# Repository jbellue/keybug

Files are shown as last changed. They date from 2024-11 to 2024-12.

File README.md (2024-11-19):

# Keybug - a small 5-keys macro keypad

It was initially designed to handle a debugger (Start/Stop/Step Into/Step Out/Step).

It runs [RMK](https://github.com/HaoboGu/rmk) (free vial!), but will be extremely simple to add to QMK. I might do that someday.

## Default Keymap

Here it is with the default keys to debug on IntelliJ:

```text
╭──────┬──────┬──────┬──────┬──────╮
│ Ctrl │  F9  │  F8  │  F7  │ Shft │
│  F2  │      │      │      │  F8  │
╰──────┴──────┴──────┴──────┴──────╯
```

## Remapping

Remapping is done through [Vial](https://vial.rocks/) on a browser supporting WedHID (i.e. Chrome).

Due to the way RMK works, reflashing probably doesn't update the keymap.

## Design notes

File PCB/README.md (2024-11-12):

# Keybug's PCB

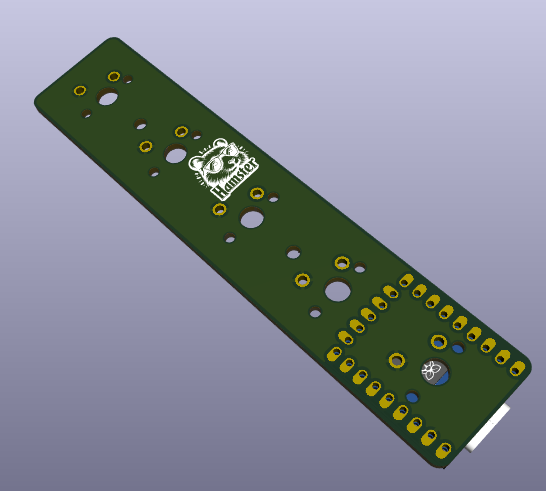
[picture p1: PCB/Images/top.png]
top view of the PCB
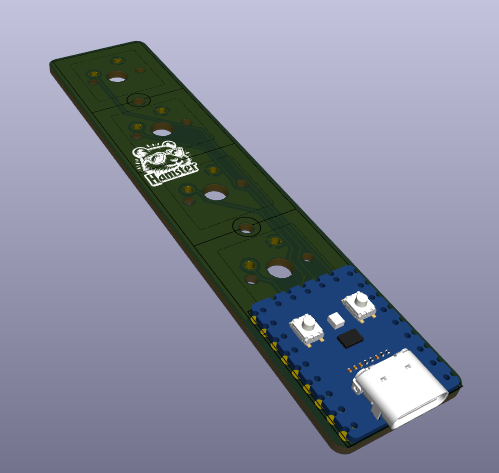
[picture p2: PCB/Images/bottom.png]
bottom view of the PCB
 

Built in Kicad8, using files from [Crides' Kleeb](https://github.com/crides/kleeb)

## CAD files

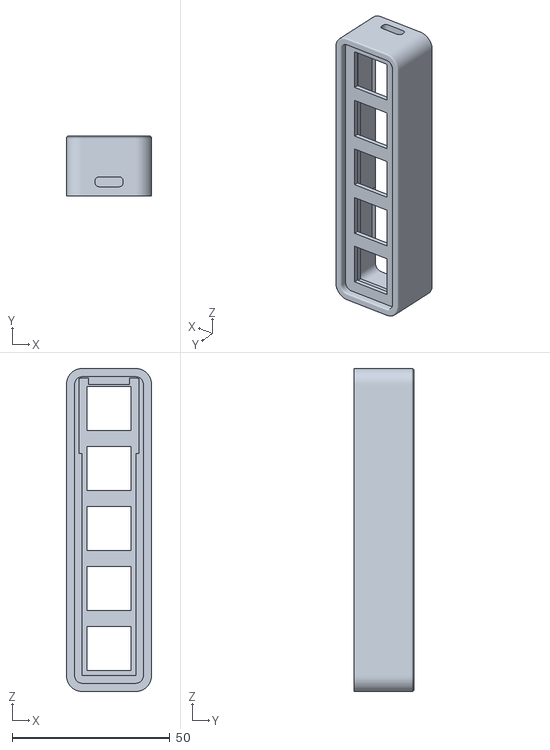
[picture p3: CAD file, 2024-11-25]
case/top.stl
27.0 x 19.0 x 102.5

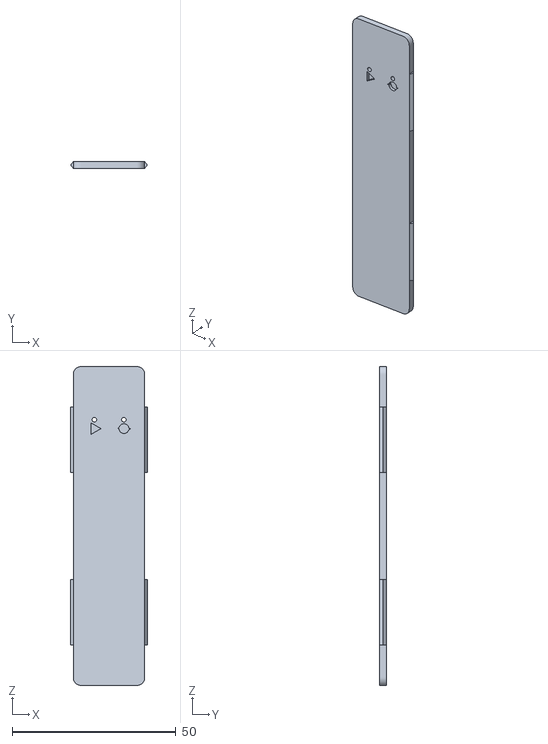
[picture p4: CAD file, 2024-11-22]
case/bottom.stl
23.4 x 2.00 x 97.3

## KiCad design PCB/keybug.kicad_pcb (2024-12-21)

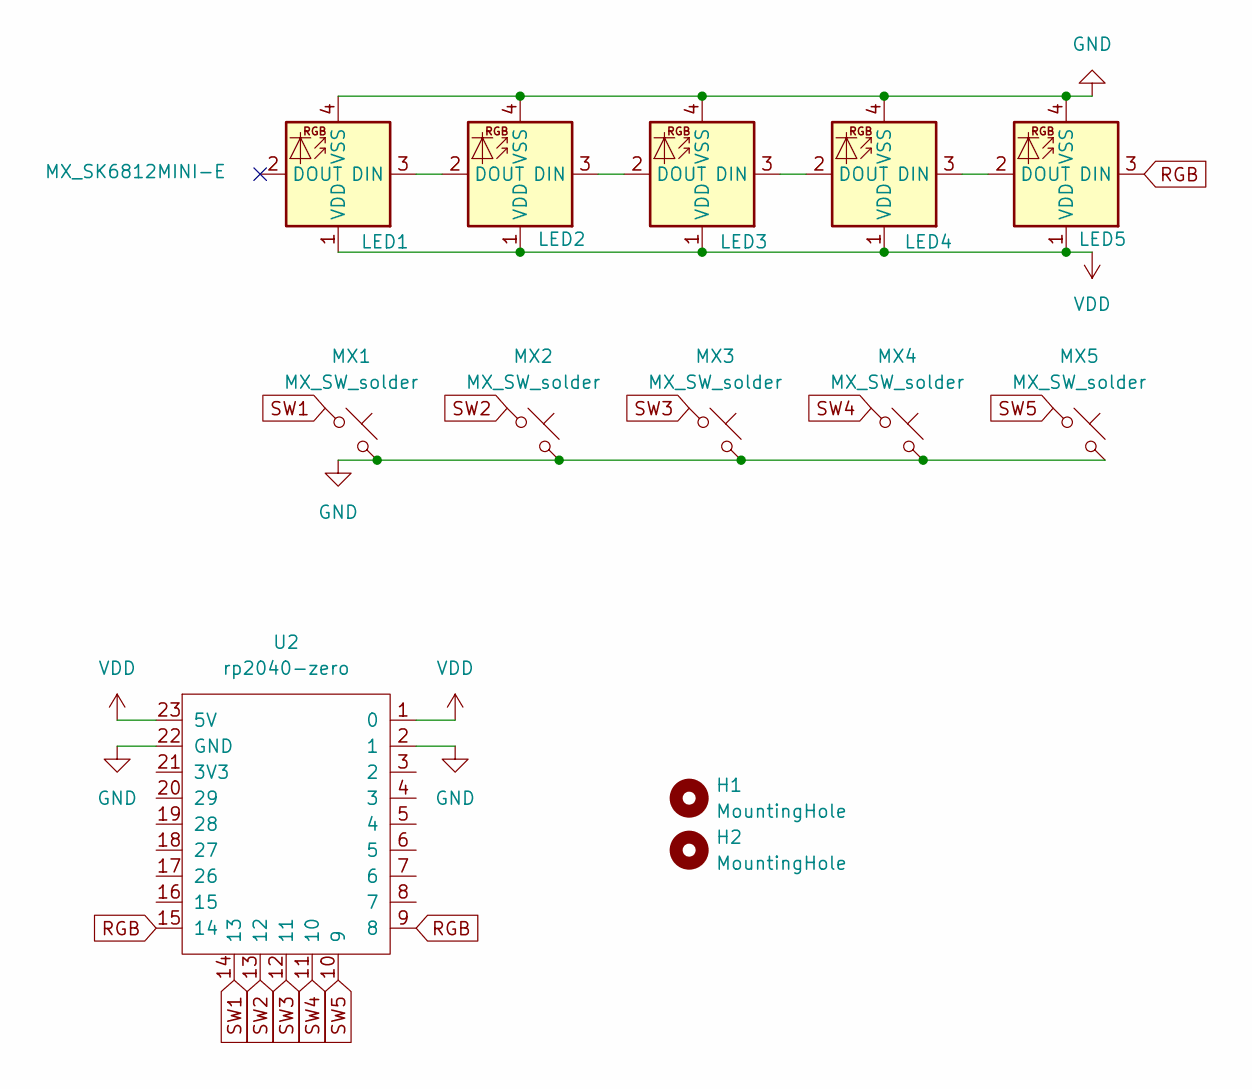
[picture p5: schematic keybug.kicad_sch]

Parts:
H1, H2: MountingHole; MountingHole_2.2mm_M2
LED1, LED2, LED3, LED4, LED5: MX_SK6812MINI-E; LED_MX_6028R-ROT
MX1, MX2, MX3, MX4, MX5: MX_SW_solder; SW_MX_1u
U2: rp2040-zero; rp2040-zero-tht

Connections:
GND: LED1.4 (VSS), LED2.4 (VSS), LED3.4 (VSS), LED4.4 (VSS), LED5.4 (VSS), MX1.2, MX2.2, MX3.2, MX4.2, MX5.2, U2.2 (1), U2.22 (GND)
unnamed: LED1.3 (DIN), LED2.2 (DOUT)
unnamed: LED2.3 (DIN), LED3.2 (DOUT)
unnamed: LED3.3 (DIN), LED4.2 (DOUT)
unnamed: LED4.3 (DIN), LED5.2 (DOUT)
RGB: LED5.3 (DIN), U2.9 (8), U2.15 (14)
SW1: MX1.1, U2.14 (13)
SW2: MX2.1, U2.13 (12)
SW3: MX3.1, U2.12 (11)
SW4: MX4.1, U2.11 (10)
SW5: MX5.1, U2.10 (9)
VDD: LED1.1 (VDD), LED2.1 (VDD), LED3.1 (VDD), LED4.1 (VDD), LED5.1 (VDD), U2.1 (0), U2.23 (5V)

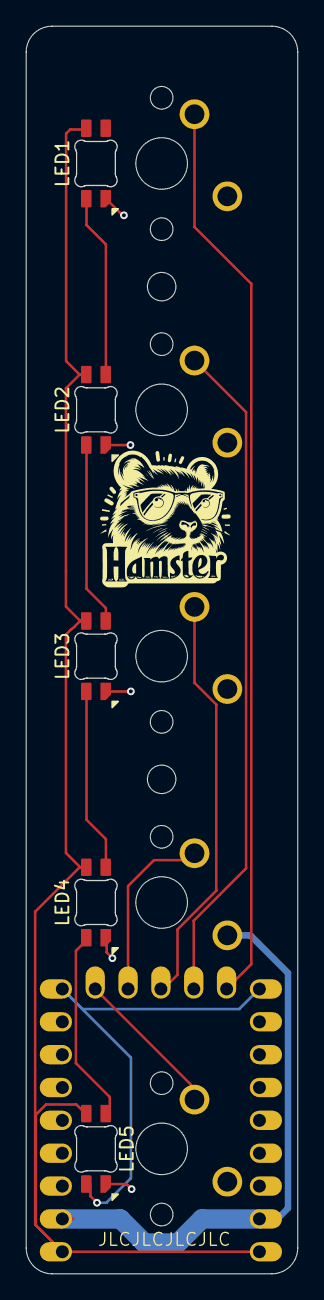
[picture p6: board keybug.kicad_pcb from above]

Board: 2 copper layers, 21.0 x 96.5 mm, 13 parts (0 on the bottom side), 12 nets.

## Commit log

2024-11-12 Add case
    [bottom.stl, top.stl]
2024-11-12 Add PCB
    [keybug.kicad_pcb, keybug.kicad_sch]
2024-11-22 PCB - put switches pads on both sides...
    [keybug.kicad_pcb]
2024-11-22 PCB - update Gerber.zip file
2024-11-22 Case - update case after first print
    [bottom.stl, top.stl]
2024-11-25 case: add recess for pins
    [top.stl]
2024-12-11 PCB+Firmware: make board reversible
    [keybug.kicad_pcb, keybug.kicad_sch]
2024-12-21 Add LEDs to PCB
    [keybug.kicad_pcb, keybug.kicad_sch]
